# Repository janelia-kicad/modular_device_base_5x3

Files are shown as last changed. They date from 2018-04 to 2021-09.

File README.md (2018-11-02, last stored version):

- [Repository Information](#org3363df3)
  - [Description](#orgd222b12)
- [Images](#orga7265e7)
- [Schematic](#orgfcf2128)
- [Gerbers](#org41eb2be)
- [Bill of Materials](#org5237e5d)
  - [PCB Parts](#org7a5a6dd)
  - [Supplemental Parts](#org5971931)
  - [Vendor Parts Lists](#orgb088364)
- [Supplemental Documentation](#org552370b)
  - [Assembly Instructions](#org9c28d25)

# Repository Information

-   **Name:** modular\_device\_base\_5x3
-   **Version:** 1.2
-   **License:** Open-Source Hardware
-   **URL:** <https://github.com/janelia-kicad/modular_device_base_5x3>
-   **Author:** Peter Polidoro
-   **Email:** peterpolidoro@gmail.com

## Description

This board is the base of 5x3 format modular devices. It is a breakout board for the microprocessor, with connections for power, communication, and top boards.

# Images

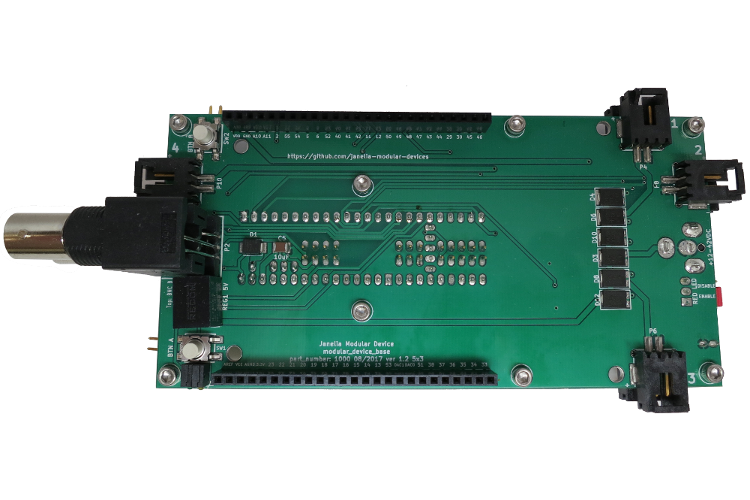
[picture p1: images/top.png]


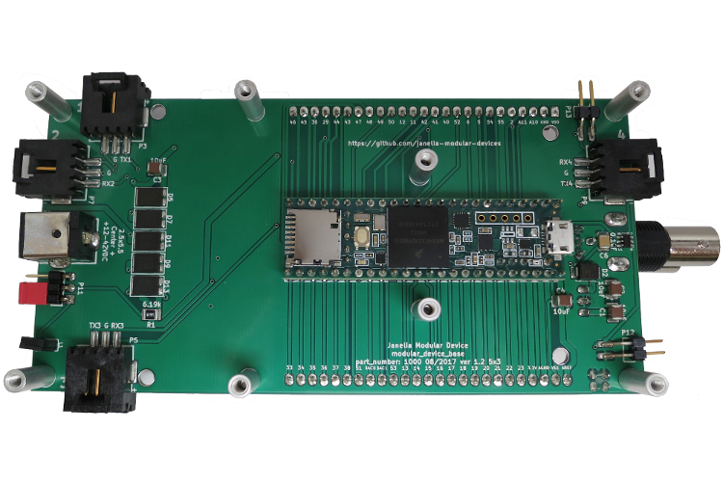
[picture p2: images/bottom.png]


# Schematic

[./schematic/modular\_device\_base\_5x3.pdf](./schematic/modular_device_base_5x3.pdf)

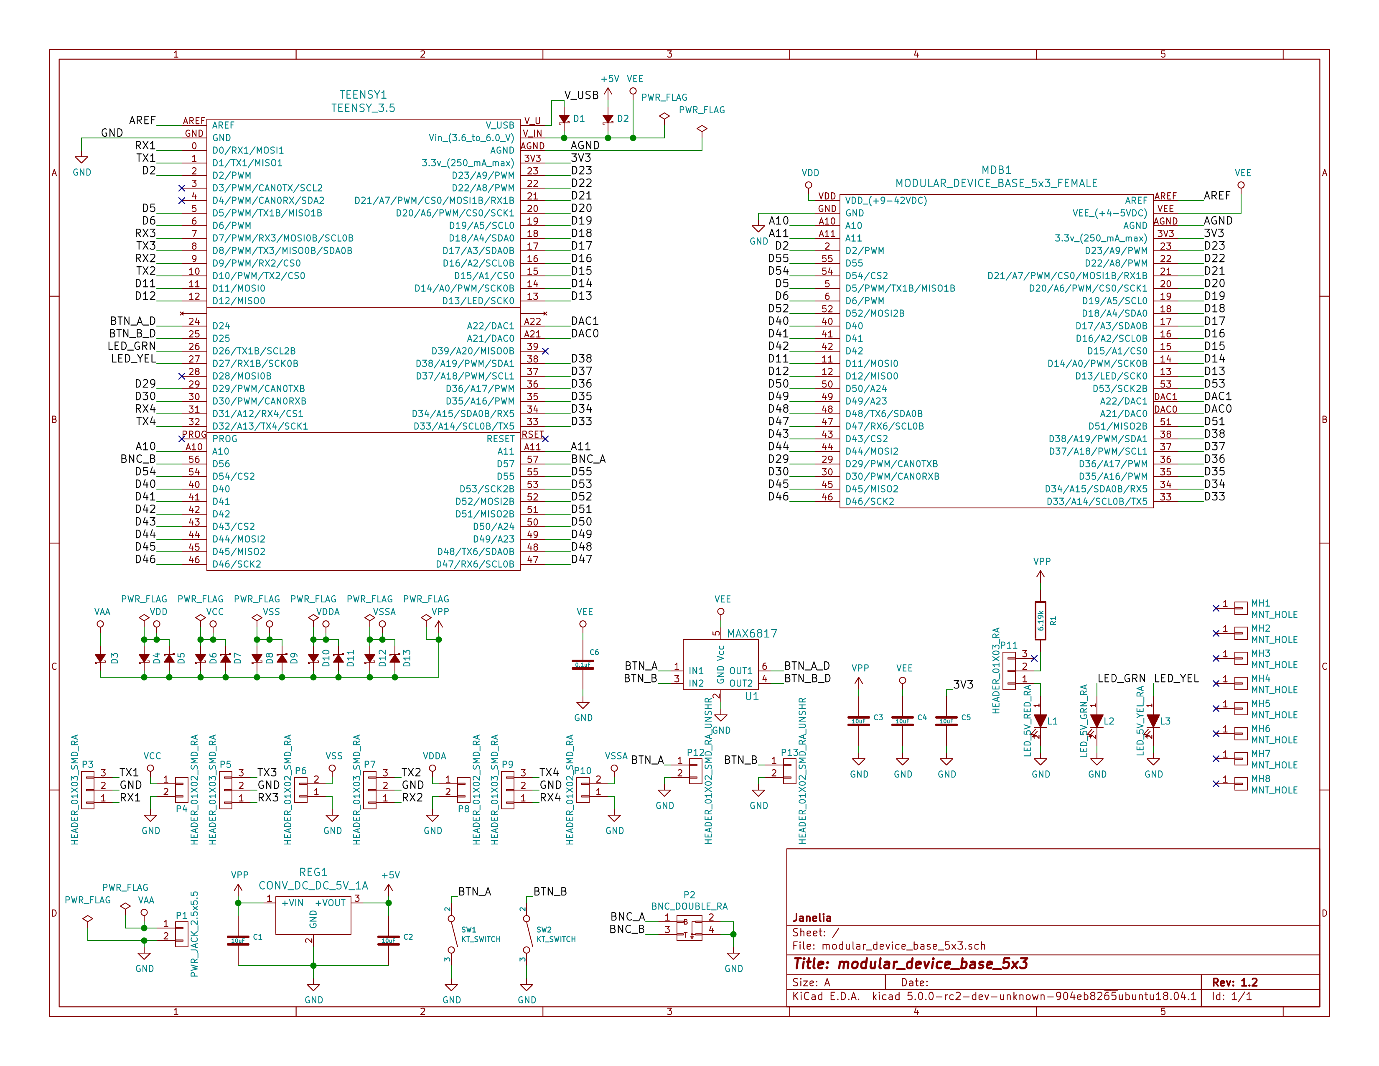
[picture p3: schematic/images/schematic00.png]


# Gerbers

Send gerbers zip file to your favorite PCB manufacturer for fabrication.

[./gerbers/modular\_device\_base\_5x3\_v1.2.zip](./gerbers/modular_device_base_5x3_v1.2.zip)

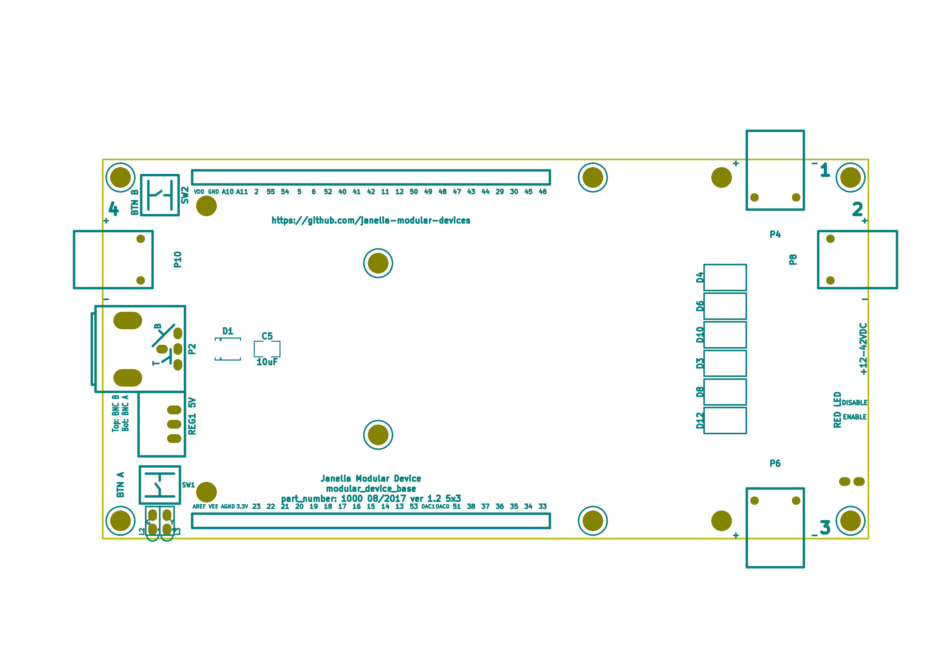
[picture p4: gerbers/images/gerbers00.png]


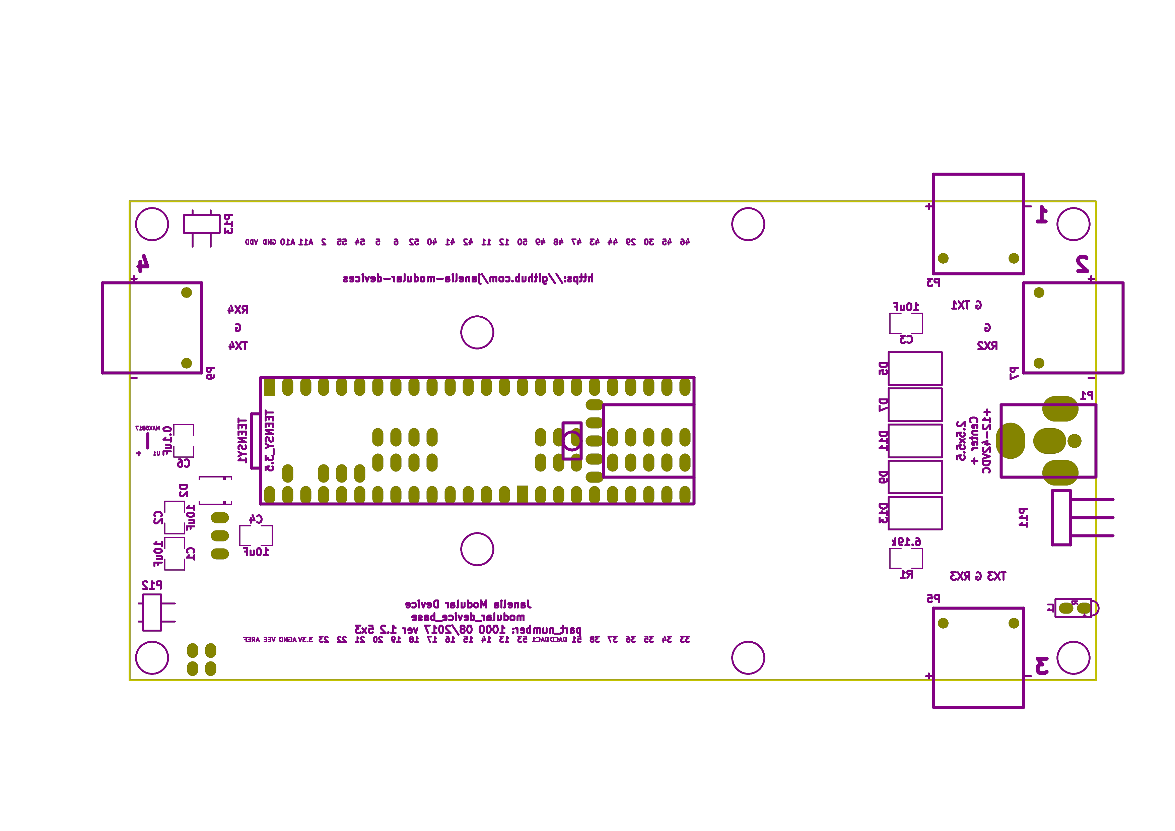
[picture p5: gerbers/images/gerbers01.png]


# Bill of Materials

## PCB Parts

| Item | Reference(s) | Quantity | PartNumber | Vendor  | Description |
|---- |--- |--- |--- |--- |--- |
| 1 | C1 C2 C3 C4 C5 | 5 | 445-4536-1-ND | digikey | CAP CER 10UF 50V 10% X7S 1210 |
| 2 | C6 | 1 | 399-13229-1-ND | digikey | CAP CER 0.1UF 100V X7R 1210 |
| 3 | D1 D2 | 2 | LSM115JE3/TR13CT-ND | digikey | DIODE SCHOTTKY 15V 1A DO214BA |
| 4 | D10 D11 D12 D13 D3 D4 D5 D6 D7 D8 D9 | 11 | 568-11697-1-ND | digikey | DIODE SCHOTTKY 45V 10A CFP15 |
| 5 | L1 | 1 | 350-1712-ND | digikey | LED 2MM 5V RT ANGLE RED PCMNT |
| 6 | L2 | 1 | 350-1717-ND | digikey | LED 2MM 5V RT ANGLE GREEN PCMNT |
| 7 | L3 | 1 | 350-1719-ND | digikey | LED 2MM 5V RT ANGLE YELLOW PCMNT |
| 8 | MDB1 | 2 | S7058-ND | digikey | 25 Position Header Through Hole Female Socket |
| 9 | MH1 MH2 MH3 MH4 MH5 MH6 MH7 MH8 | 8 | 36-2027-ND | digikey | Round Standoff Threaded 4-40 Aluminum 0.500in 0.187in |
| 10 | P1 | 1 | CP-063BH-ND | digikey | CONN PWR JACK DC 2.5X5.5 8A T/H |
| 11 | P10 P4 P6 P8 | 4 | A100903CT-ND | digikey | CONN HEADER 2POS R/A SMD GOLD |
| 12 | P11 | 1 | 732-5336-ND | digikey | CONN HEADER 3 POS RA 2.54 |
| 13 | P12 P13 | 2 | SAM10781-ND | digikey | CONN HEADER 2POS .100in SNGL SMD |
| 14 | P2 | 1 | ACX1655-ND | digikey | CONN BNC JACK R/A 75 OHM PCB |
| 15 | P3 P5 P7 P9 | 4 | A100890CT-ND | digikey | CONN HEADER 3POS R/A SMD GOLD |
| 16 | R1 | 1 | P6.19KAACT-ND | digikey | RES SMD 6.19K OHM 1% 1/2W 1210 |
| 17 | REG1 | 1 | 945-1395-5-ND | digikey | CONV DC/DC 1A 5V OUT SIP VERT |
| 18 | SW1 SW2 | 2 | CKN1860CT-ND | digikey | SWITCH TACTILE SPST-NO 1VA 32V |
| 19 | TEENSY1 | 1 | 1568-1443-ND | digikey | TEENSY 3.5 |
| 20 | U1 | 1 | MAX6817EUT+TCT-ND | digikey | IC DEBOUNCER SWITCH DUAL SOT23-6 |

## Supplemental Parts

| Item | Quantity | PartNumber | Vendor  | Description |
|---- |--- |--- |--- |--- |
| 1 | 1 | 62-1187-ND | digikey | AC/DC DESKTOP ADAPTER 24V 90W |
| 2 | 1 | 993-1037-ND | digikey | CORD 3COND NEMA PLUG 320-C5 |
| 3 | 2 | A106625CT-ND  | digikey | 14 Positions Header Unshrouded Breakaway Connector 0.100in 2 row SMD |
| 4 | 3 | S1011EC-24-ND | digikey | 14 Positions Header Unshrouded Breakaway Connector 0.100in 1 row Through |
| 5 | 1 | S9001-ND | digikey | CONN JUMPER SHORTING GOLD FLASH |
| 6 | 1 | AE10342-ND | digikey | CABLE USB-A TO MICRO USB-B 2M |
| 7 | 2 | 492-1077-ND | digikey | ROUND SPACER 4 NYLON 7/16in |

## Vendor Parts Lists

[./bom/digikey\_parts.csv](./bom/digikey_parts.csv)

[./bom/supplemental\_digikey\_parts.csv](./bom/supplemental_digikey_parts.csv)

# Supplemental Documentation

## Assembly Instructions

-   Cut the bottom trace on the Teensy board that connects the 5V pads according to these instructions <https://www.pjrc.com/teensy/external_power.html>.
-   Solder through hole header pins into every Teensy 0.1 inch header hole.
-   Solder surface mount header pins onto the bottom of the Teensy making sure they are properly aligned.
-   Solder surface mount and through hole components onto the pcb.
-   Solder the Teensy into the pcb making sure it is properly aligned.
-   Connect header jumper to RED LED enable pins.

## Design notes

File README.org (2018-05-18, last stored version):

# Created 2018-05-18 Fri 09:39
#+OPTIONS: title:nil author:nil email:nil toc:t |:t ^:nil
* Repository Information

- Name :: modular_device_base_5x3
- Version :: 1.2
- License :: Open-Source Hardware
- URL :: https://github.com/janelia-kicad/modular_device_base_5x3
- Author :: Peter Polidoro
- Email :: peterpolidoro@gmail.com

** Description

This board is the base of 5x3 format modular devices. It is a breakout board
for the microprocessor, with connections for power, communication, and top
boards.

* Images





* Schematic

[[file:./schematic/modular_device_base_5x3.pdf][./schematic/modular_device_base_5x3.pdf]]



* Gerbers

Send gerbers zip file to your favorite PCB manufacturer for fabrication.

[[file:./gerbers/modular_device_base_5x3_v1.2.zip][./gerbers/modular_device_base_5x3_v1.2.zip]]





* Bill of Materials

** PCB Parts

| Item | Reference(s)                         | Quantity | PartNumber          | Vendor  | Description                                           |
|------+--------------------------------------+----------+---------------------+---------+-------------------------------------------------------|
|    1 | C1 C2 C3 C4 C5                       |        5 | 445-4536-1-ND       | digikey | CAP CER 10UF 50V 10% X7S 1210                         |
|    2 | C6                                   |        1 | 399-13229-1-ND      | digikey | CAP CER 0.1UF 100V X7R 1210                           |
|    3 | D1 D2                                |        2 | LSM115JE3/TR13CT-ND | digikey | DIODE SCHOTTKY 15V 1A DO214BA                         |
|    4 | D10 D11 D12 D13 D3 D4 D5 D6 D7 D8 D9 |       11 | 568-11697-1-ND      | digikey | DIODE SCHOTTKY 45V 10A CFP15                          |
|    5 | L1                                   |        1 | 350-1712-ND         | digikey | LED 2MM 5V RT ANGLE RED PCMNT                         |
|    6 | L2                                   |        1 | 350-1717-ND         | digikey | LED 2MM 5V RT ANGLE GREEN PCMNT                       |
|    7 | L3                                   |        1 | 350-1719-ND         | digikey | LED 2MM 5V RT ANGLE YELLOW PCMNT                      |
|    8 | MDB1                                 |        2 | S7058-ND            | digikey | 25 Position Header Through Hole Female Socket         |
|    9 | MH1 MH2 MH3 MH4 MH5 MH6 MH7 MH8      |        8 | 36-2027-ND          | digikey | Round Standoff Threaded 4-40 Aluminum 0.500in 0.187in |
|   10 | P1                                   |        1 | CP-063BH-ND         | digikey | CONN PWR JACK DC 2.5X5.5 8A T/H                       |
|   11 | P10 P4 P6 P8                         |        4 | A100903CT-ND        | digikey | CONN HEADER 2POS R/A SMD GOLD                         |
|   12 | P11                                  |        1 | 732-5336-ND         | digikey | CONN HEADER 3 POS RA 2.54                             |
|   13 | P12 P13                              |        2 | SAM10781-ND         | digikey | CONN HEADER 2POS .100in SNGL SMD                      |
|   14 | P2                                   |        1 | ACX1655-ND          | digikey | CONN BNC JACK R/A 75 OHM PCB                          |
|   15 | P3 P5 P7 P9                          |        4 | A100890CT-ND        | digikey | CONN HEADER 3POS R/A SMD GOLD                         |
|   16 | R1                                   |        1 | P6.19KAACT-ND       | digikey | RES SMD 6.19K OHM 1% 1/2W 1210                        |
|   17 | REG1                                 |        1 | 945-1395-5-ND       | digikey | CONV DC/DC 1A 5V OUT SIP VERT                         |
|   18 | SW1 SW2                              |        2 | CKN1860CT-ND        | digikey | SWITCH TACTILE SPST-NO 1VA 32V                        |
|   19 | TEENSY1                              |        1 | 1568-1443-ND        | digikey | TEENSY 3.5                                            |
|   20 | U1                                   |        1 | MAX6817EUT+TCT-ND   | digikey | IC DEBOUNCER SWITCH DUAL SOT23-6                      |

** Supplemental Parts

| Item | Quantity | PartNumber    | Vendor  | Description                                                              |
|------+----------+---------------+---------+--------------------------------------------------------------------------|
|    1 |        1 | 62-1187-ND    | digikey | AC/DC DESKTOP ADAPTER 24V 90W                                            |
|    2 |        1 | 993-1037-ND   | digikey | CORD 3COND NEMA PLUG 320-C5                                              |
|    3 |        2 | A106625CT-ND  | digikey | 14 Positions Header Unshrouded Breakaway Connector 0.100in 2 row SMD     |
|    4 |        3 | S1011EC-24-ND | digikey | 14 Positions Header Unshrouded Breakaway Connector 0.100in 1 row Through |
|    5 |        1 | S9001-ND      | digikey | CONN JUMPER SHORTING GOLD FLASH                                          |
|    6 |        1 | AE10342-ND    | digikey | CABLE USB-A TO MICRO USB-B 2M                                            |
|    7 |        2 | 492-1077-ND   | digikey | ROUND SPACER 4 NYLON 7/16in                                              |

** Vendor Parts Lists

[[file:./bom/digikey_parts.csv][./bom/digikey_parts.csv]]

[[file:./bom/supplemental_digikey_parts.csv][./bom/supplemental_digikey_parts.csv]]

* Supplemental Documentation

** Assembly Instructions

- Cut the bottom trace on the Teensy board that connects the 5V pads according
  to these instructions [[https://www.pjrc.com/teensy/external_power.html]].
- Solder through hole header pins into every Teensy 0.1 inch header hole.
- Solder surface mount header pins onto the bottom of the Teensy making sure
  they are properly aligned.
- Solder surface mount and through hole components onto the pcb.
- Solder the Teensy into the pcb making sure it is properly aligned.
- Connect header jumper to RED LED enable pins.

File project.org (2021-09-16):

* Header                                                           :noexport:

  #+MACRO: name modular_device_base_5x3
  #+MACRO: version 2.0
  #+MACRO: license Open-Source Hardware
  #+MACRO: url https://github.com/janelia-kicad/modular_device_base_5x3
  #+AUTHOR: Peter Polidoro
  #+EMAIL: peter@polidoro.io

* Description

  This board is the base of 5x3 format modular devices. It is a breakout board
  for the microprocessor, with connections for power, communication, and top
  boards.

* Assembly Instructions

  - Solder surface mount and through hole components onto the pcb.

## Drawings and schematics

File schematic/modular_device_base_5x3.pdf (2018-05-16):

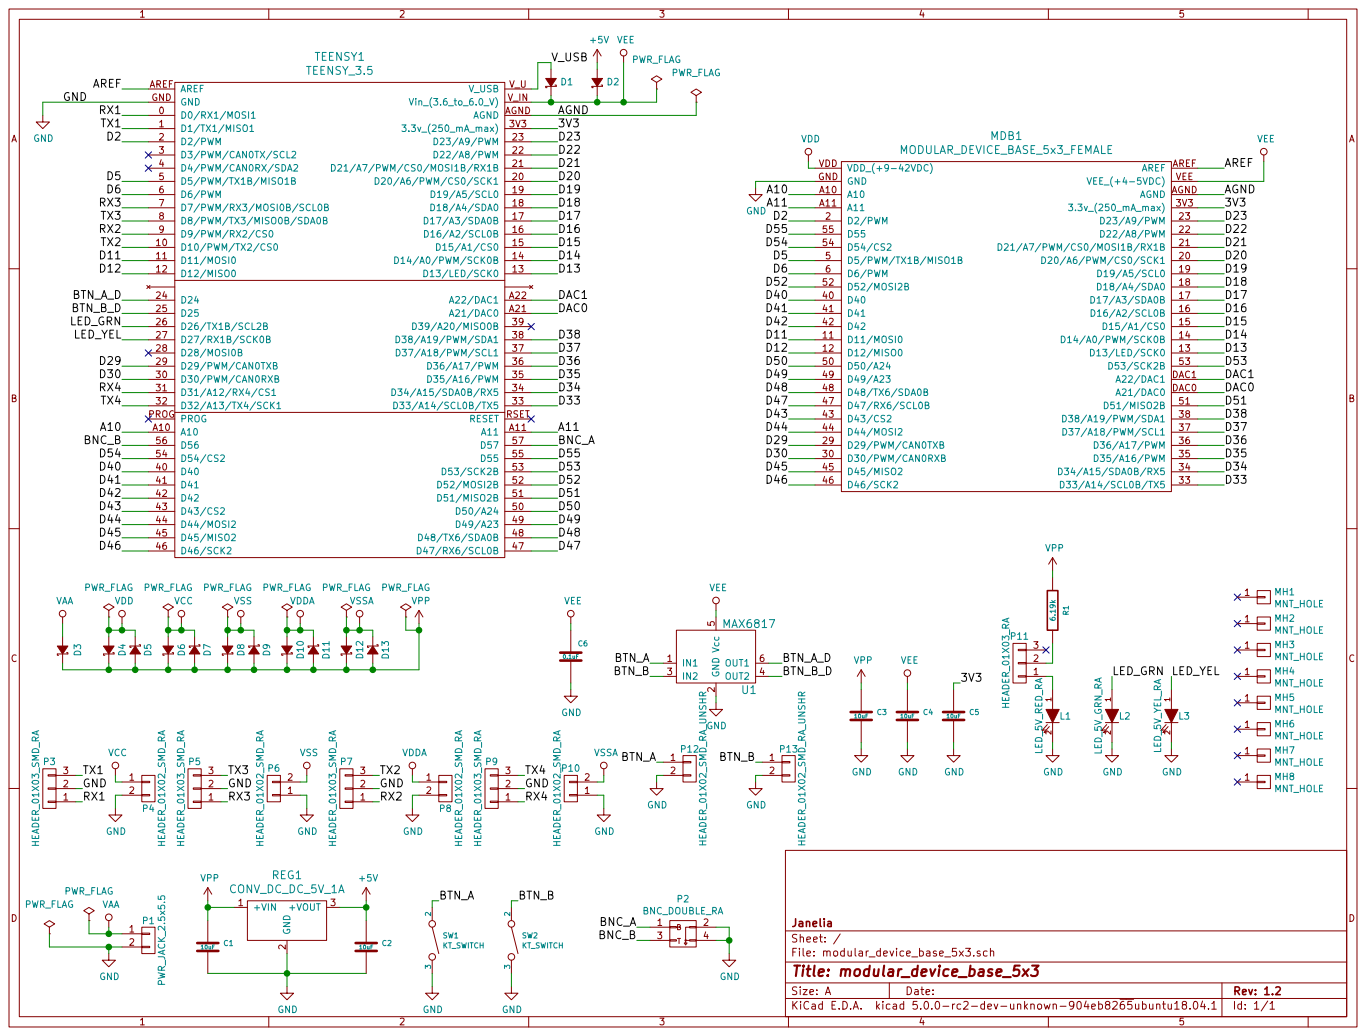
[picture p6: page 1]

File: modular_device_base_5x3.sch Sheet: / Janelia

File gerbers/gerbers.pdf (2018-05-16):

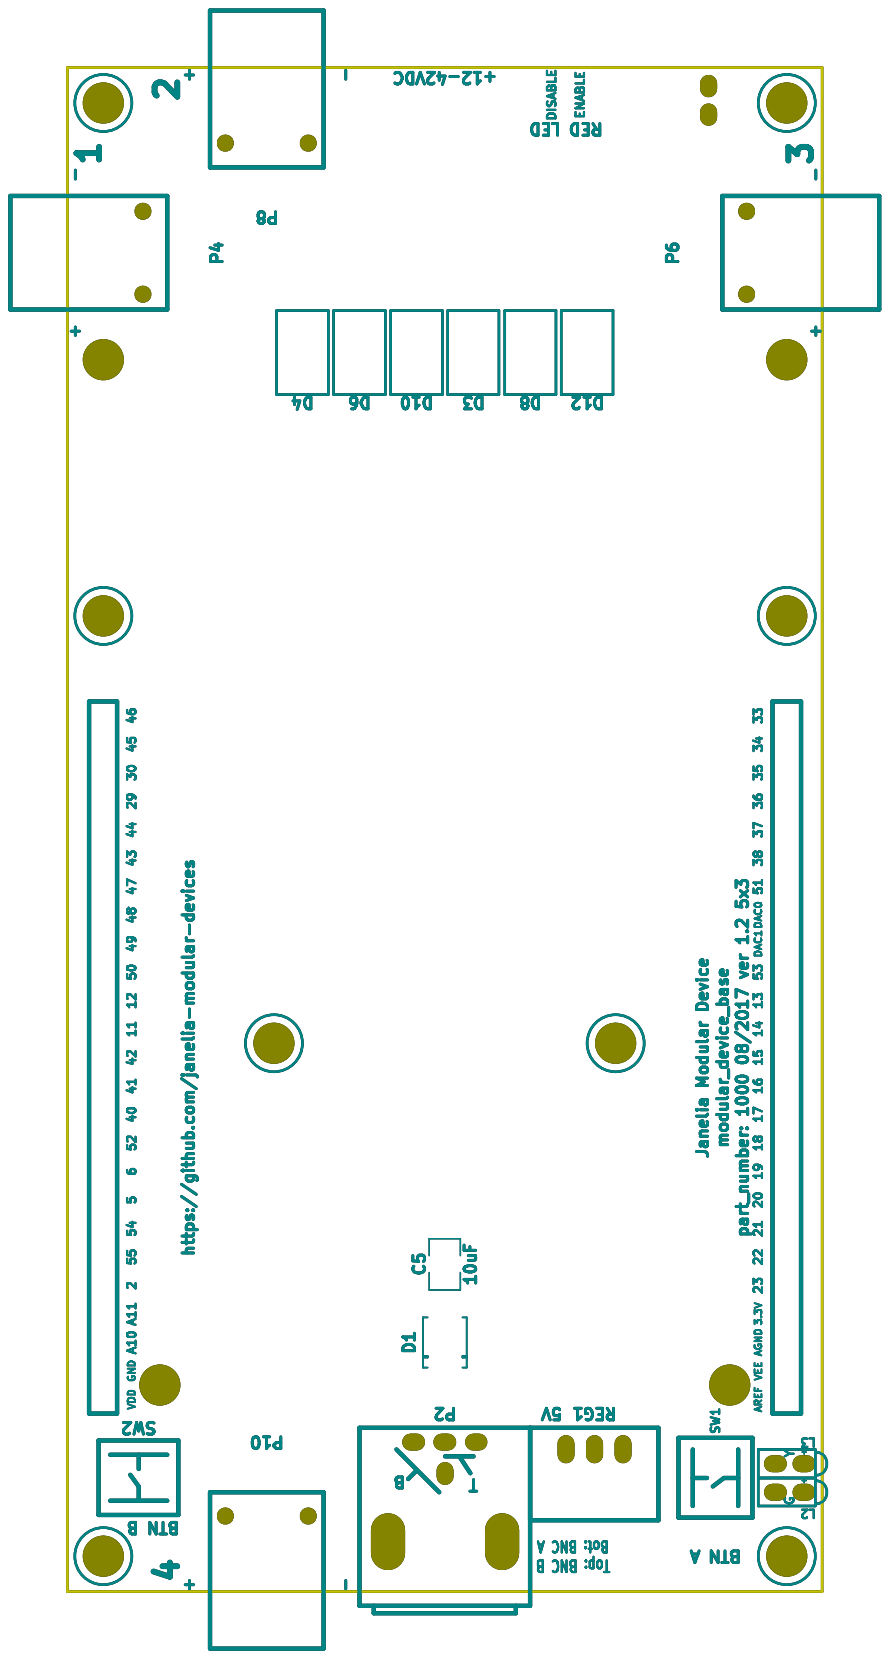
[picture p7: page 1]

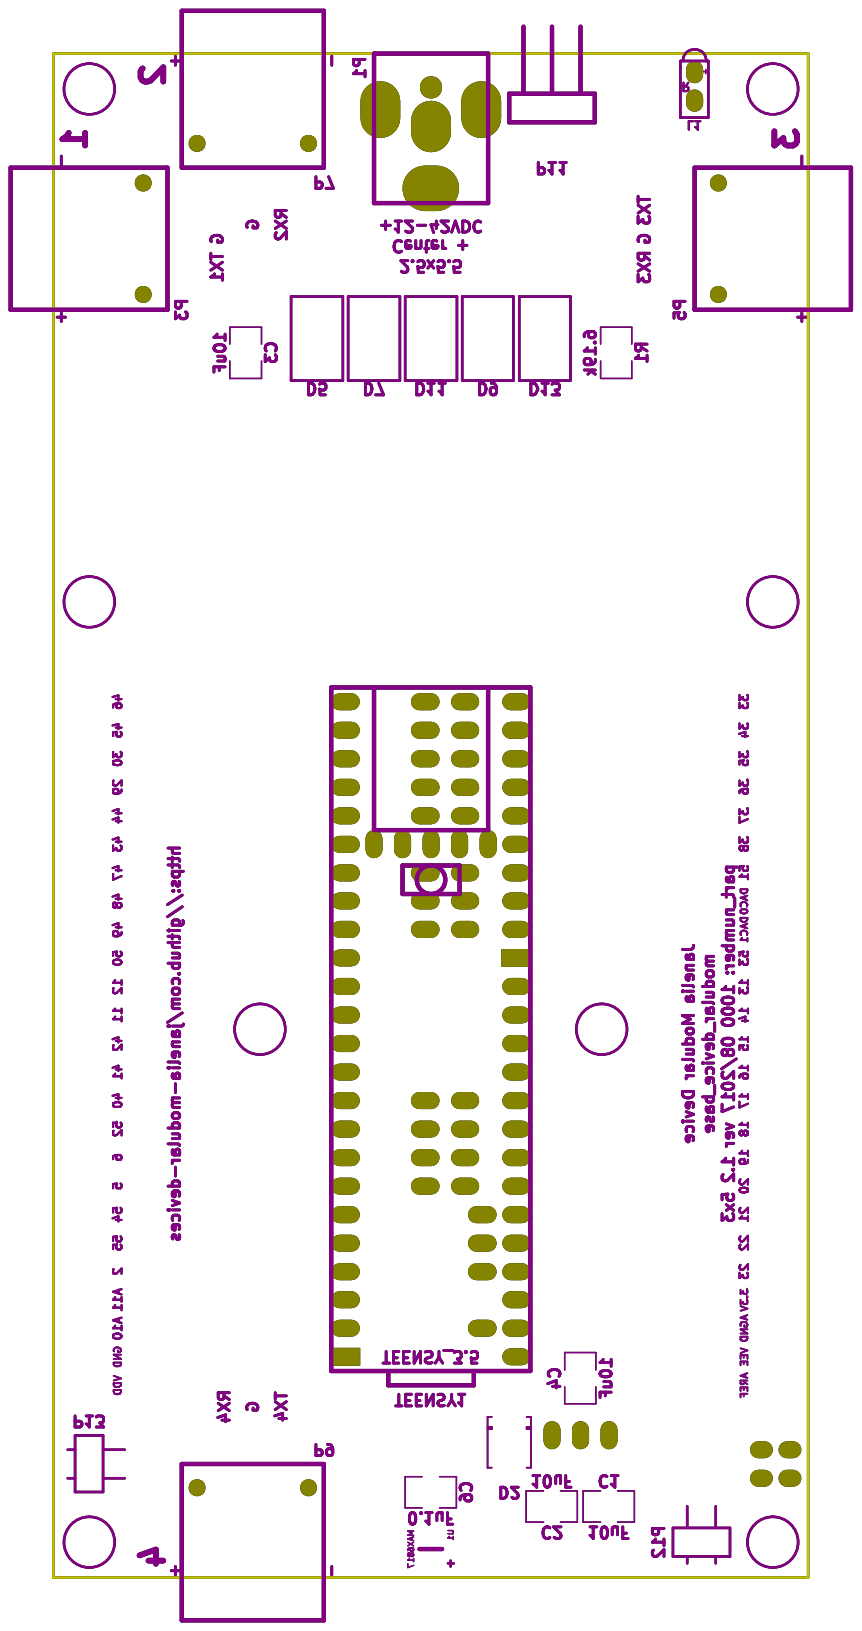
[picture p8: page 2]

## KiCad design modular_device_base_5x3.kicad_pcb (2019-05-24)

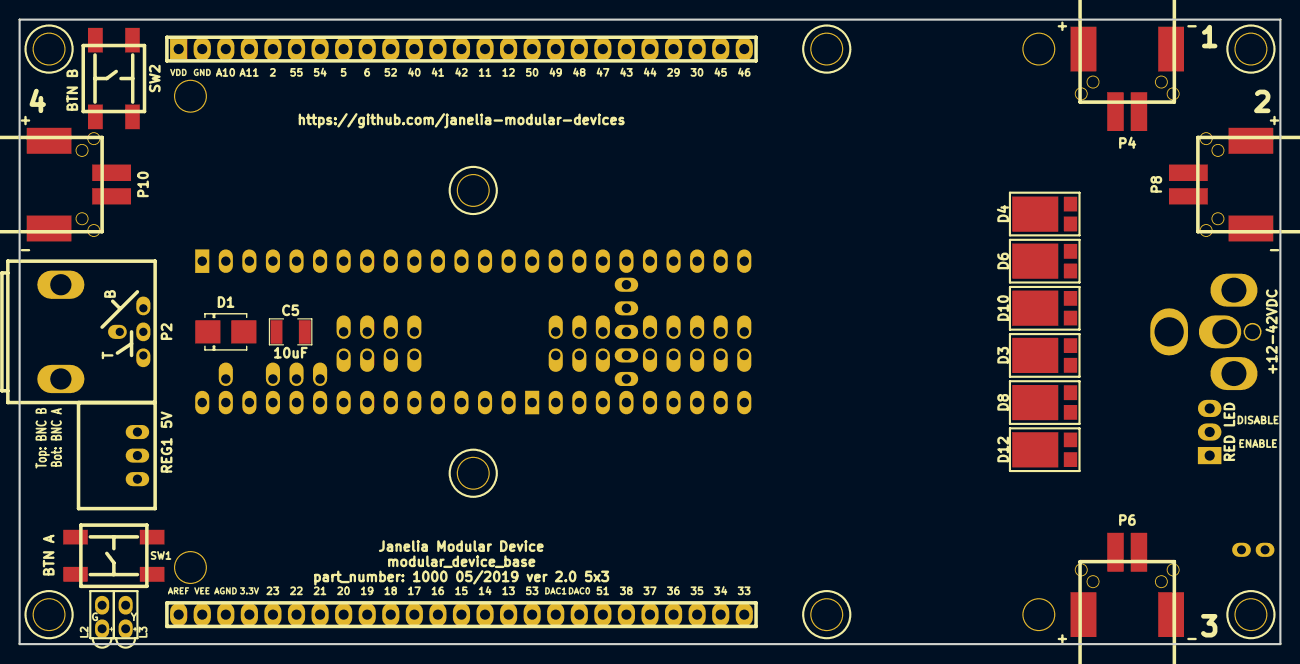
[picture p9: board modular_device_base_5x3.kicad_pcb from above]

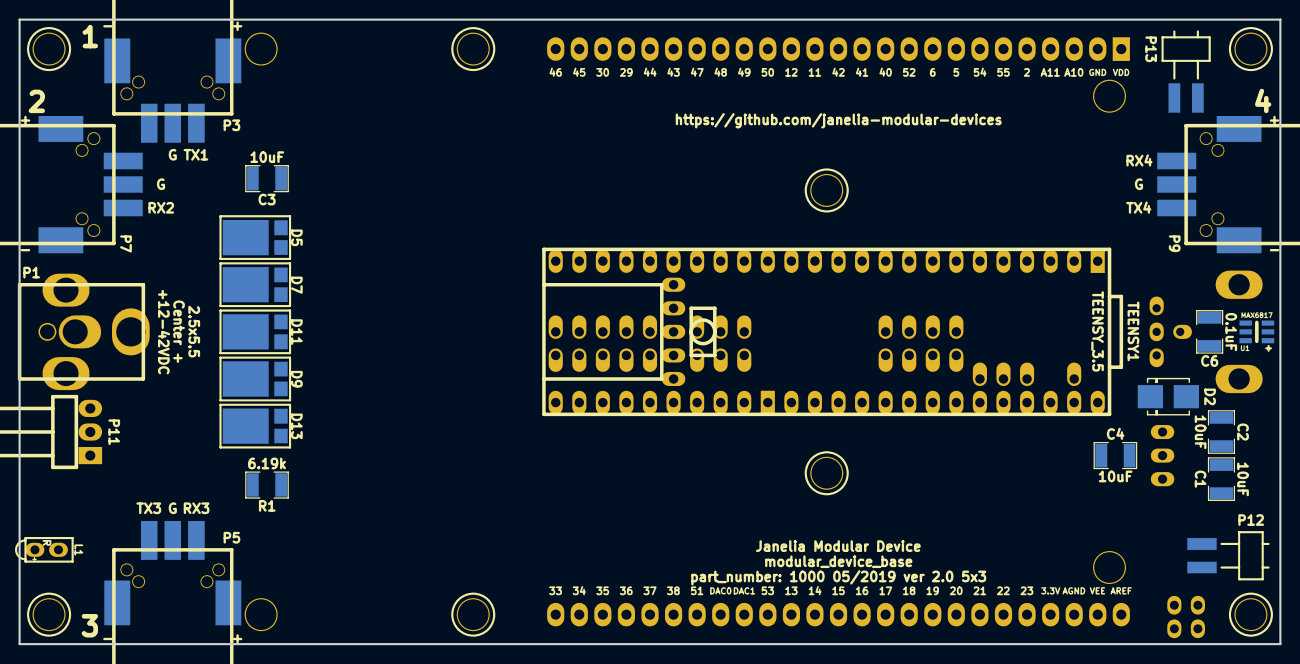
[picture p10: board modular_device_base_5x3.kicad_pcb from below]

Board: 2 copper layers, 135.9 x 67.3 mm, 50 parts (23 on the bottom side), 76 nets, no tracks yet.

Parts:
C1, C2, C3, C4, C5: 10uF; SM1210
C6: 0.1uF; SM1210
D1, D2: diode_schottky_15V_1A; DO-214BA
D3, D4, D5, D6, D7, D8, D9, D10, D11, D12, D13: diode_schottky_45V_10A; CFP15
L1: LED_5V_RED_RA; LED_555-2XXX
L2: LED_5V_GRN_RA; LED_555-2XXX
L3: LED_5V_YEL_RA; LED_555-2XXX
MDB1: MODULAR_DEVICE_BASE_5x3_FEMALE; MODULAR_DEVICE_BASE_5X3_FEMALE
MH1, MH2, MH3, MH4, MH5, MH6, MH7, MH8: MNT_HOLE; MOUNTING_HOLE_4-40
P1: PWR_JACK_2.5x5.5; DCJACK_2PIN_HIGHCURRENT
P2: BNC_DOUBLE_RA; BNC_DOUBLE
P3, P5, P7, P9: HEADER_01X03_SMD_RA; Header_3_Pin_SMD_RA
P4, P6, P8, P10: HEADER_01X02_SMD_RA; Header_2_Pin_SMD_RA
P11: HEADER_01X03_RA; Header_3_Pin_RA
P12, P13: HEADER_01X02_SMD_RA_UNSHR; Header_2_Pin_SMD_RA_UNSHR
R1: 6.19k; SM1210
REG1: CONV_DC_DC_5V_1A; DC_DC_CONV_R78C
SW1, SW2: KT_SWITCH
TEENSY1: TEENSY_3.5
U1: MAX6817

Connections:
+5V: C2.1, D2.2, REG1.3
/3V3: C5.1, MDB1.3V3, TEENSY1.3V3
/A10: MDB1.A10, TEENSY1.A10
/A11: MDB1.A11, TEENSY1.A11
/AGND: MDB1.AGND, TEENSY1.AGND
/AREF: MDB1.AREF, TEENSY1.AREF
/BNC_A: P2.1, TEENSY1.57
/BNC_B: P2.3, TEENSY1.56
/BTN_A: P12.1, SW1.2, U1.1
/BTN_A_D: TEENSY1.24, U1.6
/BTN_B: P13.1, SW2.2, U1.3
/BTN_B_D: TEENSY1.25, U1.4
/D2: MDB1.2, TEENSY1.2
/D5: MDB1.5, TEENSY1.5
/D6: MDB1.6, TEENSY1.6
/D11: MDB1.11, TEENSY1.11
/D12: MDB1.12, TEENSY1.12
/D13: MDB1.13, TEENSY1.13
/D14: MDB1.14, TEENSY1.14
/D15: MDB1.15, TEENSY1.15
/D16: MDB1.16, TEENSY1.16
/D17: MDB1.17, TEENSY1.17
/D18: MDB1.18, TEENSY1.18
/D19: MDB1.19, TEENSY1.19
/D20: MDB1.20, TEENSY1.20
/D21: MDB1.21, TEENSY1.21
/D22: MDB1.22, TEENSY1.22
/D23: MDB1.23, TEENSY1.23
/D29: MDB1.29, TEENSY1.29
/D30: MDB1.30, TEENSY1.30
/D33: MDB1.33, TEENSY1.33
/D34: MDB1.34, TEENSY1.34
/D35: MDB1.35, TEENSY1.35
/D36: MDB1.36, TEENSY1.36
/D37: MDB1.37, TEENSY1.37
/D38: MDB1.38, TEENSY1.38
/D40: MDB1.40, TEENSY1.40
/D41: MDB1.41, TEENSY1.41
/D42: MDB1.42, TEENSY1.42
/D43: MDB1.43, TEENSY1.43
/D44: MDB1.44, TEENSY1.44
/D45: MDB1.45, TEENSY1.45
/D46: MDB1.46, TEENSY1.46
/D47: MDB1.47, TEENSY1.47
/D48: MDB1.48, TEENSY1.48
/D49: MDB1.49, TEENSY1.49
/D50: MDB1.50, TEENSY1.50
/D51: MDB1.51, TEENSY1.51
/D52: MDB1.52, TEENSY1.52
/D53: MDB1.53, TEENSY1.53
/D54: MDB1.54, TEENSY1.54
/D55: MDB1.55, TEENSY1.55
/DAC0: MDB1.DAC0, TEENSY1.A21
/DAC1: MDB1.DAC1, TEENSY1.A22
/LED_GRN: L2.1, TEENSY1.26
/LED_YEL: L3.1, TEENSY1.27
/RX1: P3.1, TEENSY1.0
/RX2: P7.1, TEENSY1.9
/RX3: P5.1, TEENSY1.7
/RX4: P9.1, TEENSY1.31
/TX1: P3.3, TEENSY1.1
/TX2: P7.3, TEENSY1.10
/TX3: P5.3, TEENSY1.8
/TX4: P9.3, TEENSY1.32
/V_USB: D1.2, TEENSY1.V_U
GND: C1.2, C2.2, C3.2, C4.2, C5.2, C6.2, L1.2, L2.2, L3.2, MDB1.GND, P1.2, P2.2, P2.4, P3.2, P4.2, P5.2, P6.1, P7.2, P8.2, P9.2, P10.1, P12.2, P13.2, REG1.2, SW1.3, SW2.3, TEENSY1.GND, U1.2
unnamed: L1.1, P11.1
unnamed: P11.2, R1.2
VAA: D3.2, P1.1
VCC: D6.2, D7.1, P4.1
VDD: D4.2, D5.1, MDB1.VDD
VDDA: D10.2, D11.1, P8.1
VEE: C4.1, C6.1, D1.1, D2.1, MDB1.VEE, TEENSY1.V_IN, U1.5
VPP: C1.1, C3.1, D3.1, D4.1, D5.2, D6.1, D7.2, D8.1, D9.2, D10.1, D11.2, D12.1, D13.2, R1.1, REG1.1
VSS: D8.2, D9.1, P6.2
VSSA: D12.2, D13.1, P10.2

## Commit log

2017-02-03 Initial commit.
    [bom_pcb.csv, bom_pcb_add.csv, digikey_order.csv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]
2017-02-03 footprints: -> modular_device_base_5x3:.
    [modular_device_base_5x3.dsn, modular_device_base_5x3.kicad_pcb, modular_device_base_5x3.sch]
2017-02-03 Added TEENSY_3.5 footprint.
    [modular_device_base_5x3.kicad_pcb, modular_device_base_5x3.sch]
2017-02-06 Added Teensy3.5 component.
    [modular_device_base_5x3.sch]
2017-02-06 Progress towards v1.0.
    [modular_device_base_5x3.sch]
2017-02-07 Progress towards new modifications.
    [bom_pcb.csv, digikey_order_pcb.csv, modular_device_base_5x3.kicad_pcb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]
2017-02-08 Finished design ver 1.0.
    [modular_device_base_5x3-B.Cu.gbl, modular_device_base_5x3-B.Mask.gbs, modular_device_base_5x3-B.SilkS.gbo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]
2017-02-08 Updated boms.
    [bom_pcb_add.csv, digikey_order.csv, digikey_order_pcb.csv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]
2017-05-23 Added components and footprints.
    [modular_device_base_5x3.kicad_pcb, modular_device_base_5x3.sch]
2017-05-23 Progress towards v1.1.
    [bom_pcb.csv, digikey_order_pcb.csv, modular_device_base_5x3.kicad_pcb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]
2017-05-24 More progress towards v1.1.
    [bom_pcb.csv, digikey_order_pcb.csv, modular_device_base_5x3.kicad_pcb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]
2017-05-25 Completed v1.1.
    [bom_pcb.csv, bom_pcb_add.csv, digikey_order.csv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]
2017-05-26 Added standoffs to bom.
    [bom_pcb_add.csv, digikey_order.csv, digikey_order_pcb_add.csv]
2017-05-26 Moved edges of MDB_5x3 footprint.
    [modular_device_base_5x3.kicad_pcb]
2017-08-08 Progress towards v1.2.
    [bom_pcb.csv, digikey_order_pcb.csv, modular_device_base_5x3.dsn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]
2017-08-09 Finished v1.2.
    [digikey_order.csv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]
2017-09-13 Updated 0.1uF capacitors.
    [bom_pcb.csv, digikey_order.csv, digikey_order_pcb.csv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]
2018-01-08 Updated to v4.
    [modular_device_base_5x3.sch]
2018-05-16 Added documentation.
    [bom_pcb.csv, bom_pcb_add.csv, digikey_order.csv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]
2018-05-16 Remove frame ref from gerber images.
2018-05-17 Added assembly instructions.
2018-05-17 Renamed to gerbers.pdf.
2018-08-12 Marked extra Teensy 3.5 Pins.
2018-08-12 Updated teensy pin markings.
2018-08-23 Added digikey_order.
    [digikey_order.csv]
2018-08-23 Added supplemental parts.
    [digikey_order.csv]
2019-05-24 Add schematics
    [modular_device_base_5x3.kicad_pcb, modular_device_base_5x3.sch, modular_device_base_5x3_female.sch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]
2019-06-03 teensy_3.5_plus -> teensy_3.5
    [modular_device_base_5x3.sch, teensy_3.5.sch]
2021-09-21 Remove ignored files
    [modular_device_base_5x3.dsn]
